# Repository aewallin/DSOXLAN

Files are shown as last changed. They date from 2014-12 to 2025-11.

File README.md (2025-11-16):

DSOXLAN
=======

This is a simple Ethernet interface-card for Agilent/Keysight
DSO-X 2000 and 3000 series oscilloscopes. The original Agilent/Keysight 
DSOXLAN module (about 326 euros + VAT as of December 2014)
also includes VGA output, while this simple card provides only LAN.

Many thanks to "georges80" on the EEVBlog forum
for the original schematic and PCB layout.

Components:
* Ethernet jack, WÜRTH 7499010121A
* 2pcs 470R 0805 resistor
* 1pcs 10R 0805 resistor
* 1pcs 1n 0805 capacitor

Files:
* Kicad: schematic, PCB, project, cmp, netlist
* non-standard footprints in /footprints: Ethernet magjack, 2x40-pin card-edge connector.

3D print components for case obtained from

https://www.eevblog.com/forum/projects/diy-dsoxlan-interface-for-keysight-oscilloscopes/msg4323214/#msg4323214

The mounting holes for the screws are 3.2 mm in diameter, so M3 screws
fit well.

Apparently they have been authored by Jay_Diddy_B.

Released under the CERN OHL. See http://ohwr.org/cernohl

Images
======

Using the 3D printed front cover and spacers, the entire module looks like:

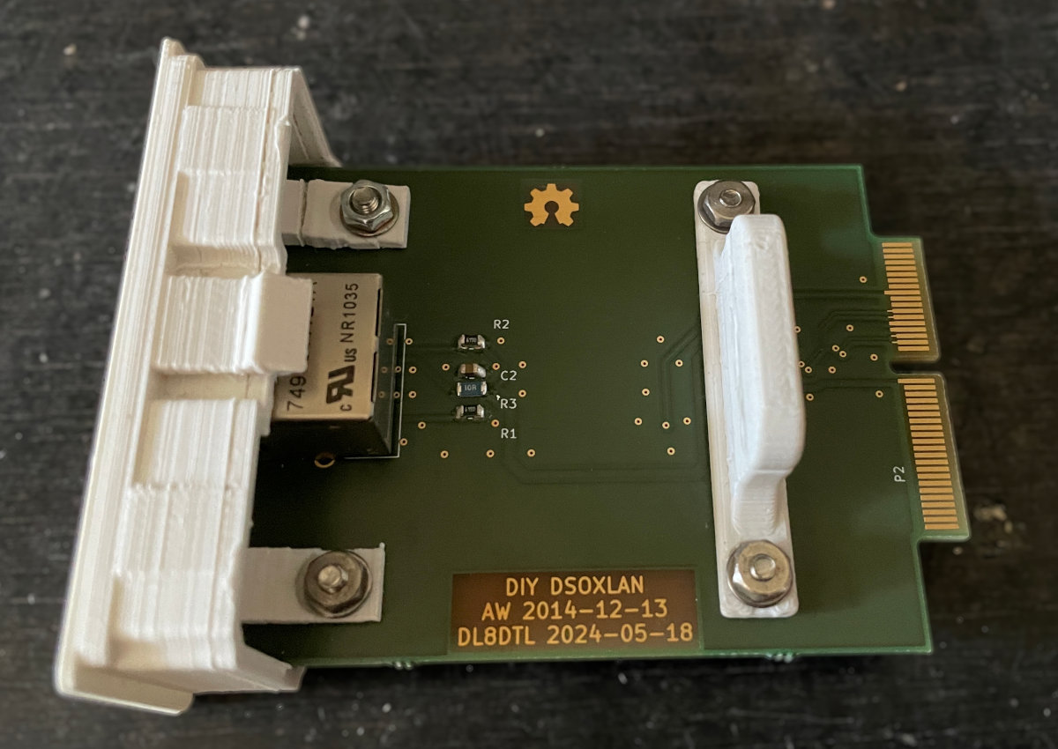
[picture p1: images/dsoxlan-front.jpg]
DSOXLAN front side

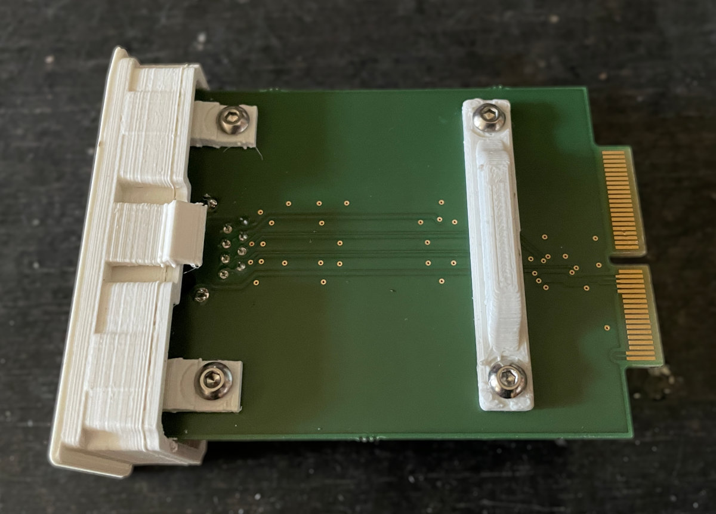
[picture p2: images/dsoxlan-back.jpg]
DSOXLAN back side


The oscilloscope features a built-in HTTP server.
The LAN settings page from the oscilloscope:

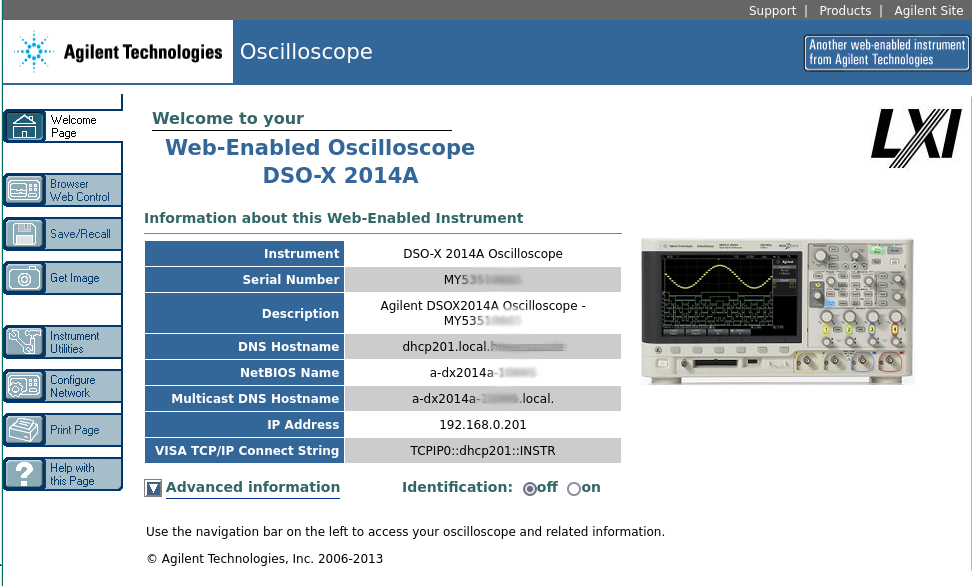
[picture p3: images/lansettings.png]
DSO-X LAN settings


There are also options for remote control straight from the HTTP
server. Some of them require Java, but when selecting the "Tablet"
mode, it offers an HTML5 control option:

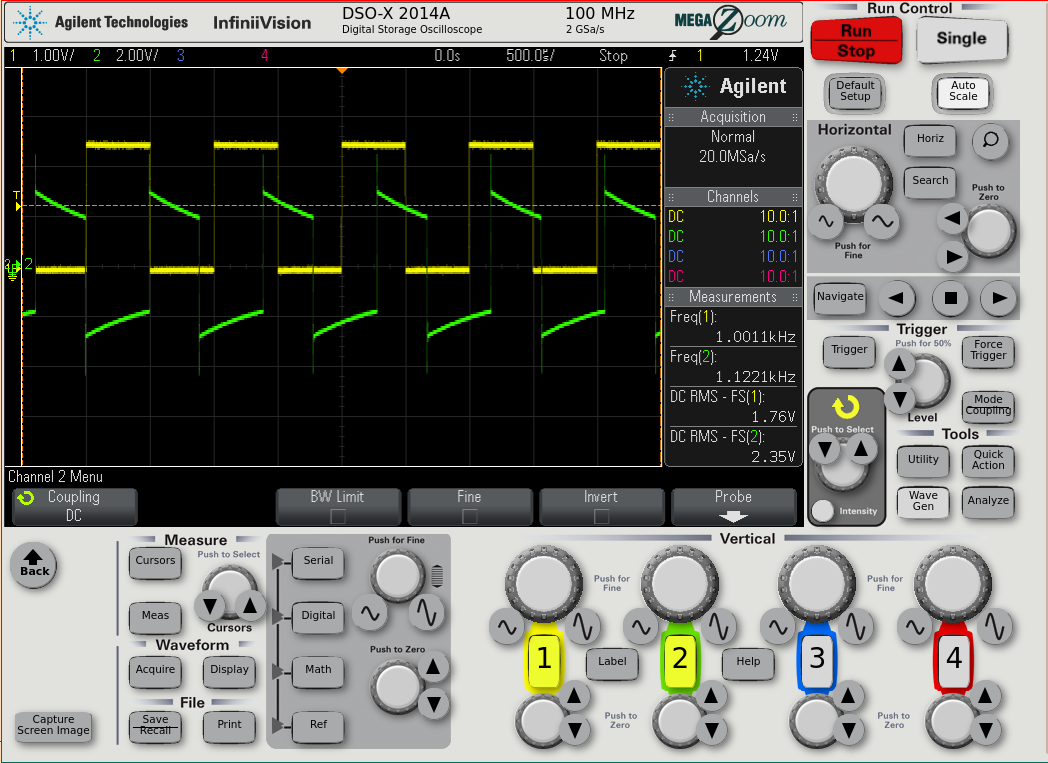
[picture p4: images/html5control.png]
DSO-X HTML5 screen


(Note: the above module has been built using a slightly different version
of the Würth RJ45 jack, 7499011121A. If anyone wants to use exactly
these, see https://github.com/dl8dtl/DSOXLAN/tree/WE7499011121A )

Links
=====
* https://web.archive.org/web/20200225205940/http://anagram.net/nuts/DSOXLAN/
* http://www.anderswallin.net/2014/12/diy-dsoxlan/

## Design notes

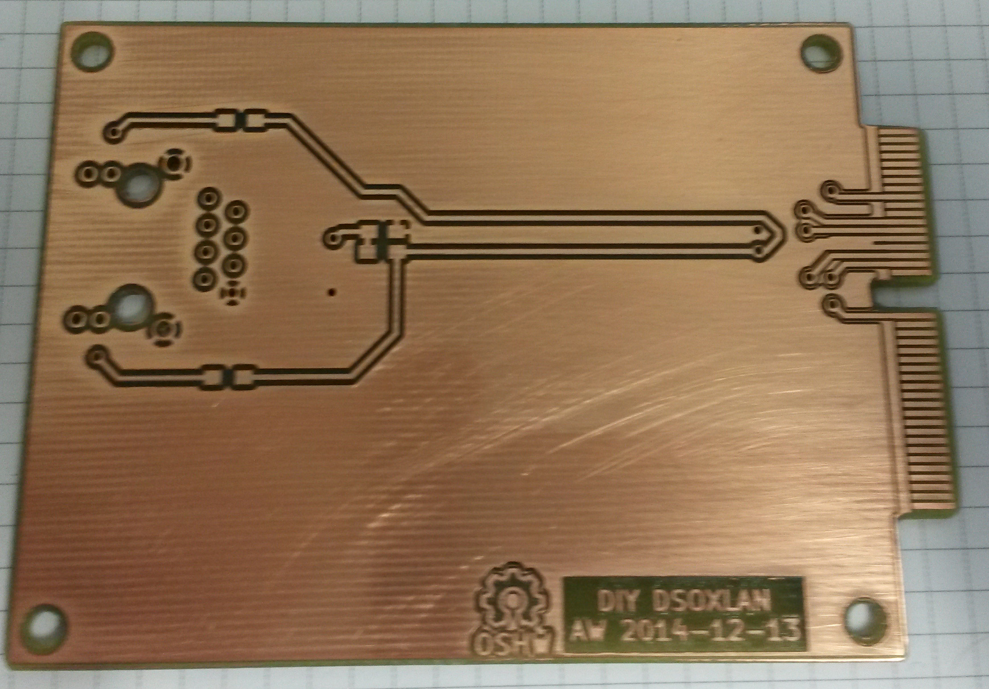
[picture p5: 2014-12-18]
dsoxlan_pcb_2014-12-17.jpg

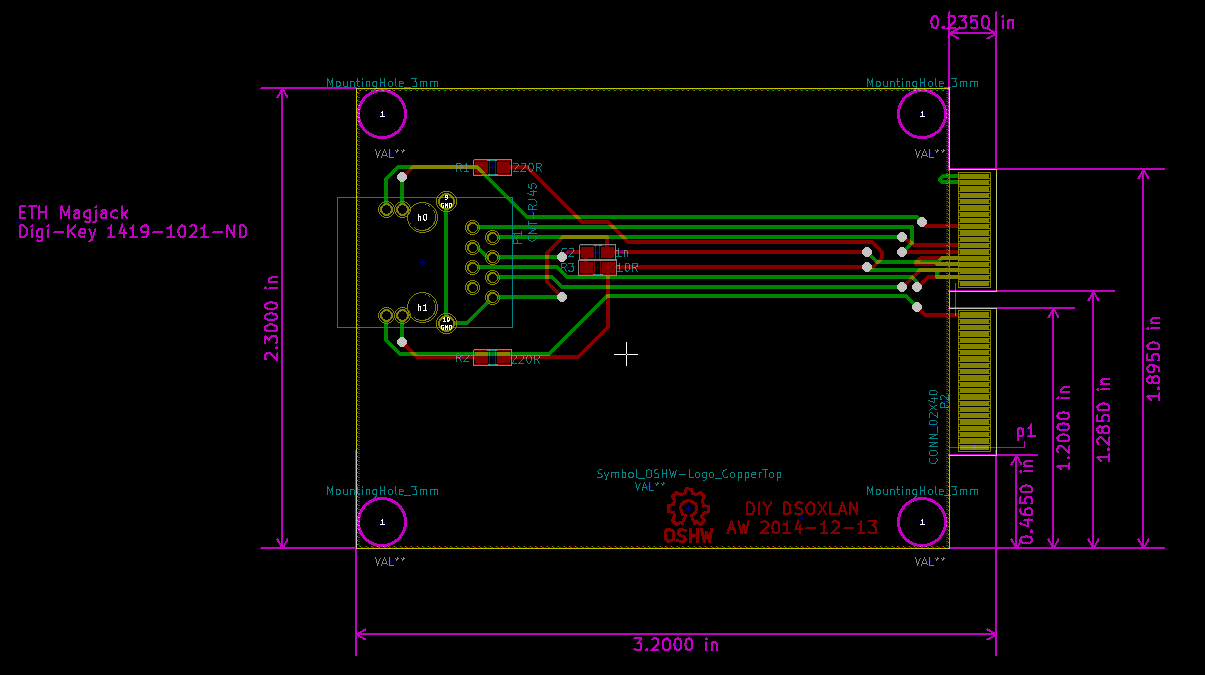
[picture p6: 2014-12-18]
dsoxlan_kicad_pcb.png

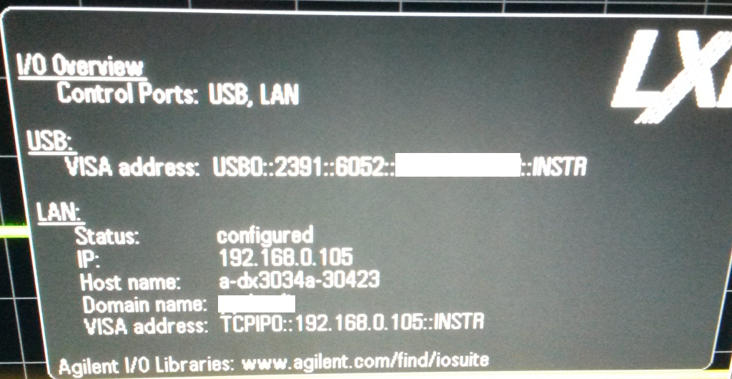
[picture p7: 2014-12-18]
dsoxlan_LAN-settings.jpg

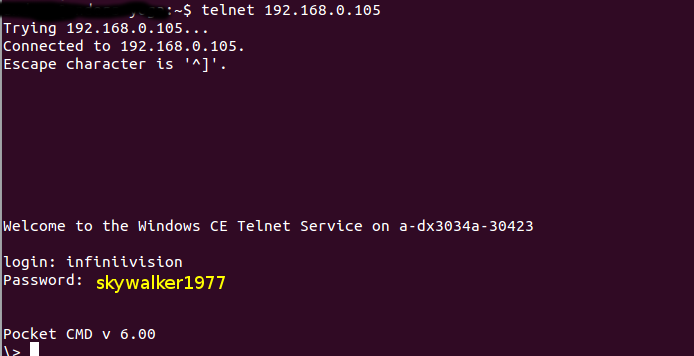
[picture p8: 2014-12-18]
dsoxlan_telnet.png

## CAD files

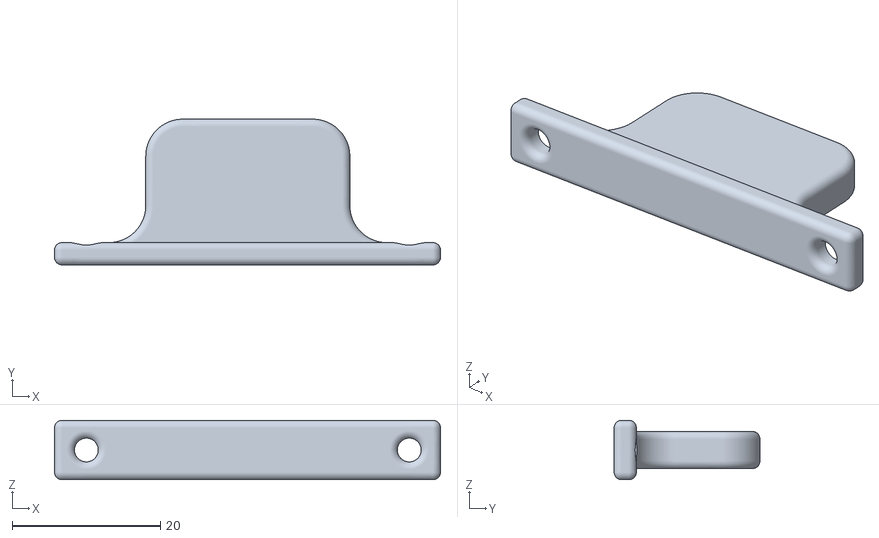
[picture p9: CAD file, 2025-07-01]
3Dmodels/Spacer 2b.stl
52.0 x 19.6 x 8.00

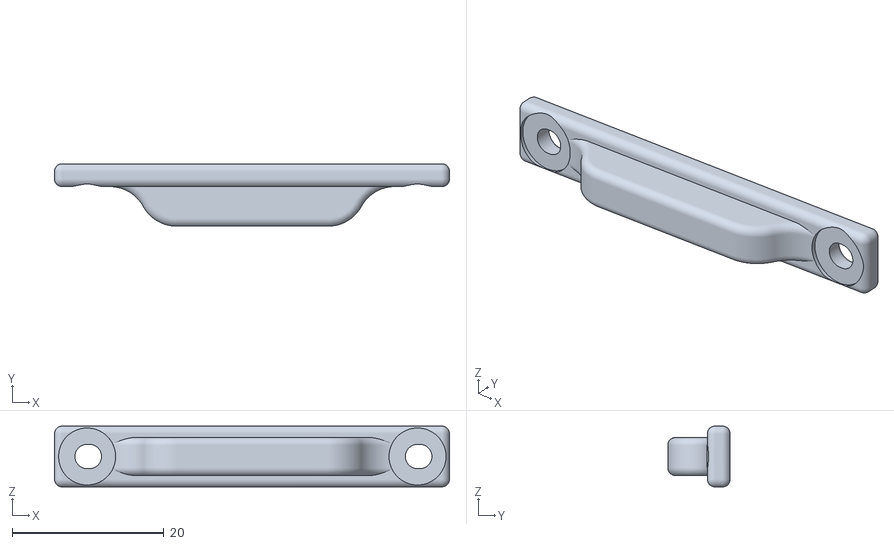
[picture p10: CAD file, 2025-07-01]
3Dmodels/Spacer 1a.stl
52.0 x 8.21 x 8.00

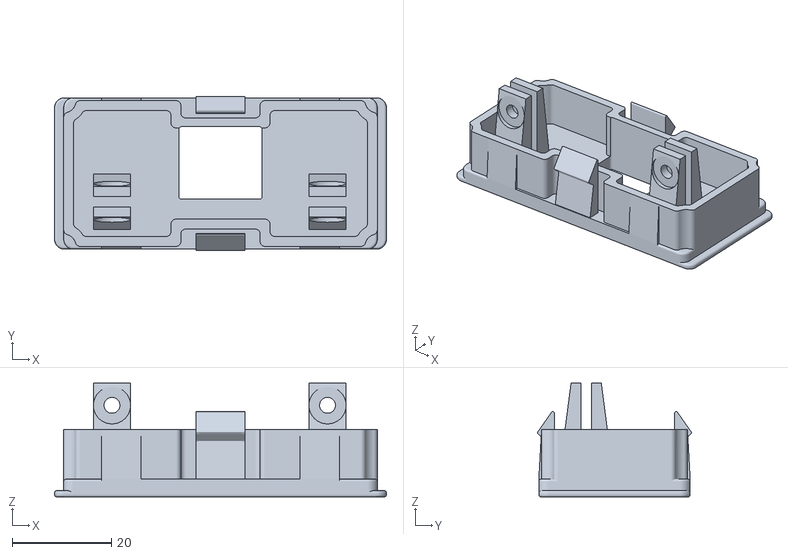
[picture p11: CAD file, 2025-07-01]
3Dmodels/Lid.stl
67.0 x 31.1 x 23.0

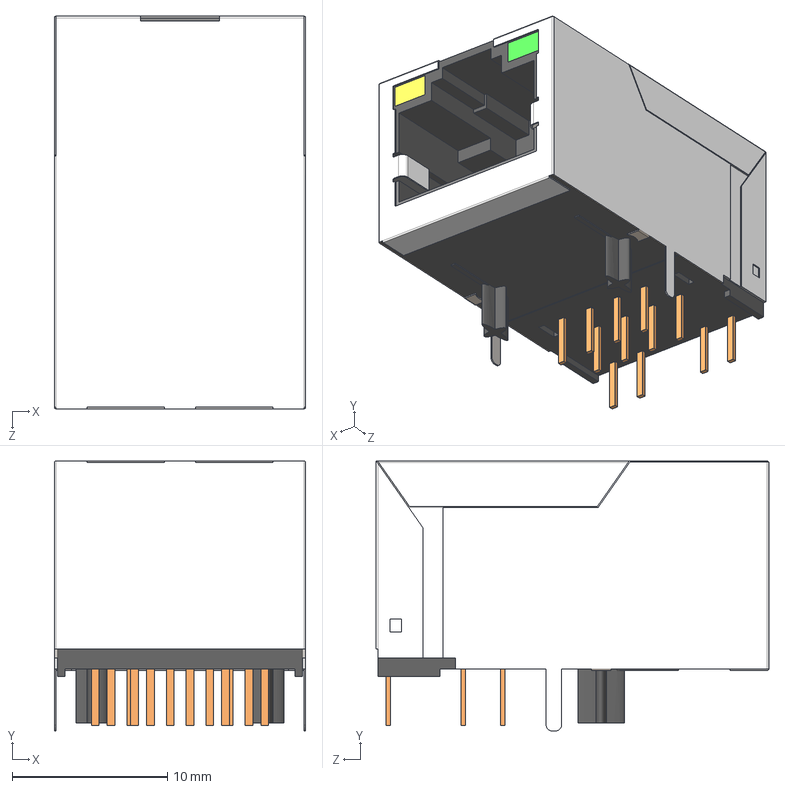
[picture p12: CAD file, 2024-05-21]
3Dmodels/7499010121A.stp
16.2 x 17.4 x 25.3 mm

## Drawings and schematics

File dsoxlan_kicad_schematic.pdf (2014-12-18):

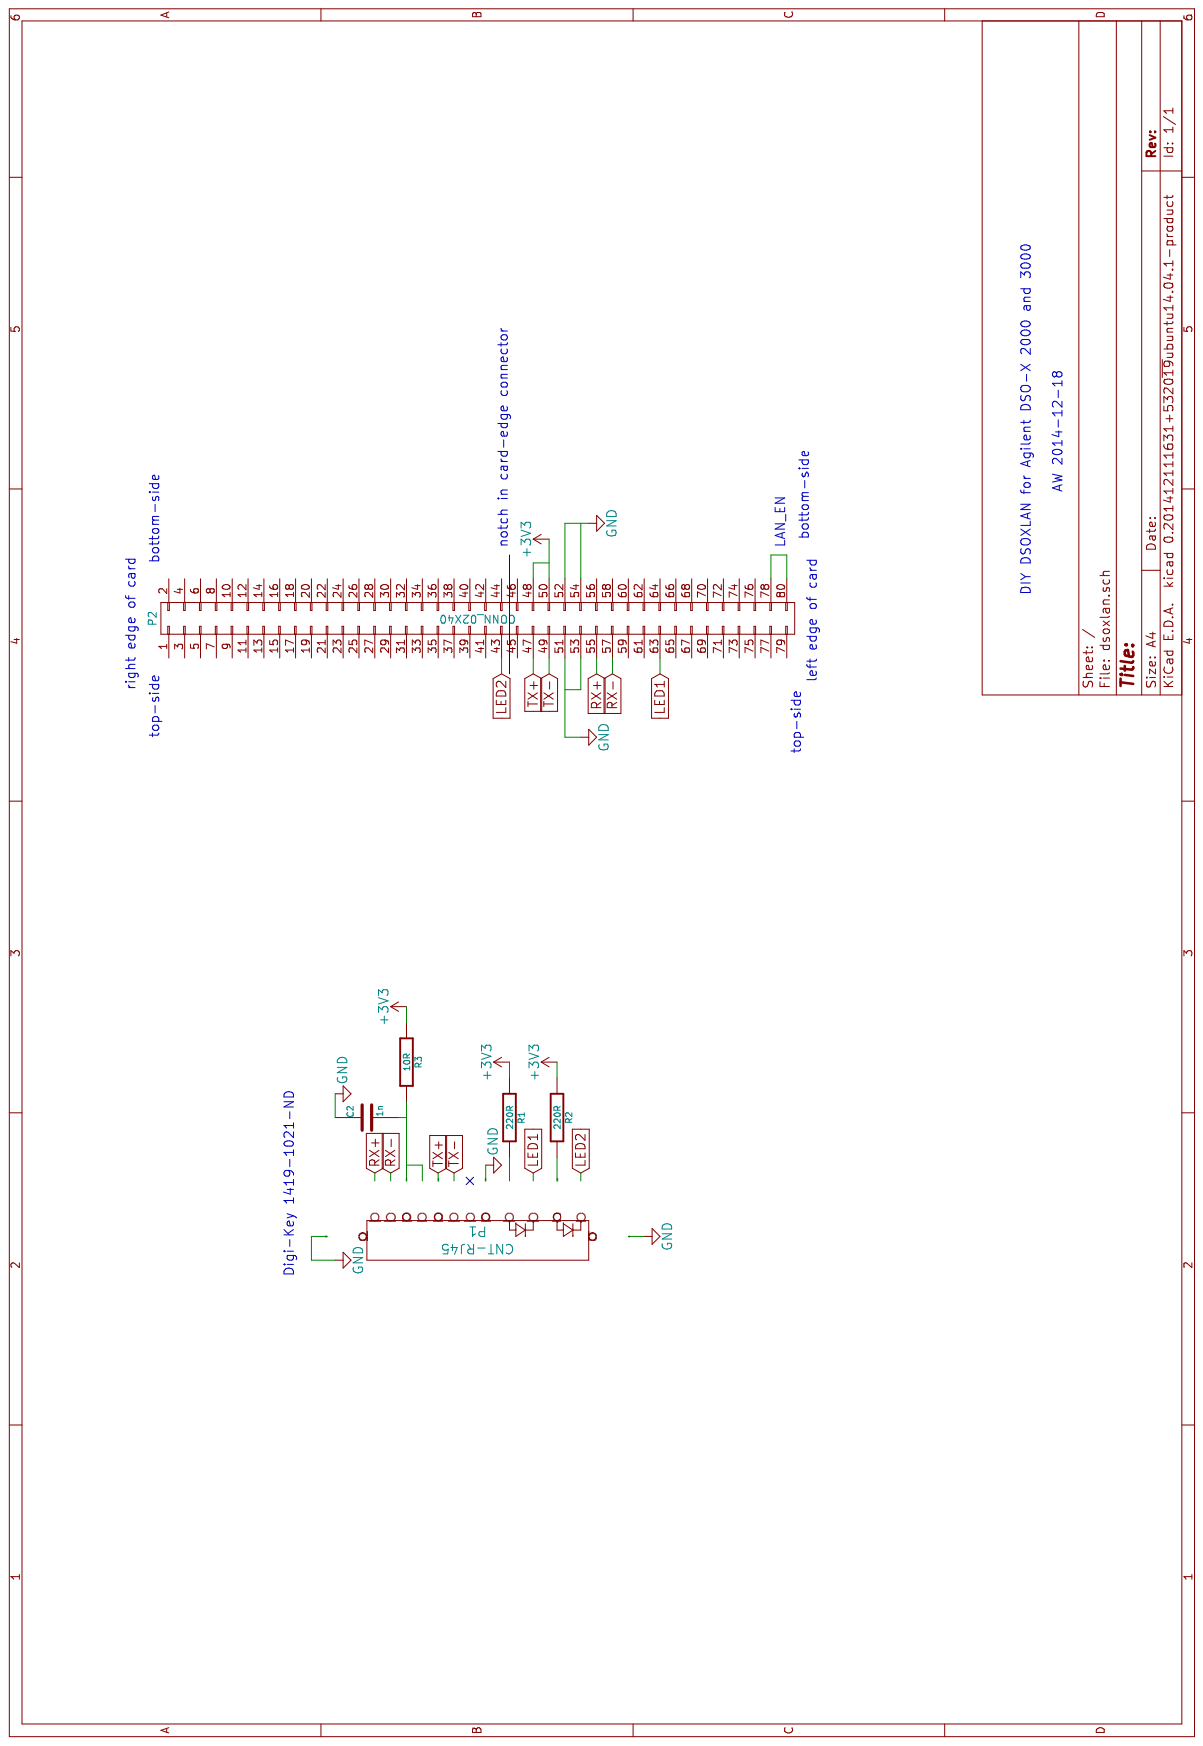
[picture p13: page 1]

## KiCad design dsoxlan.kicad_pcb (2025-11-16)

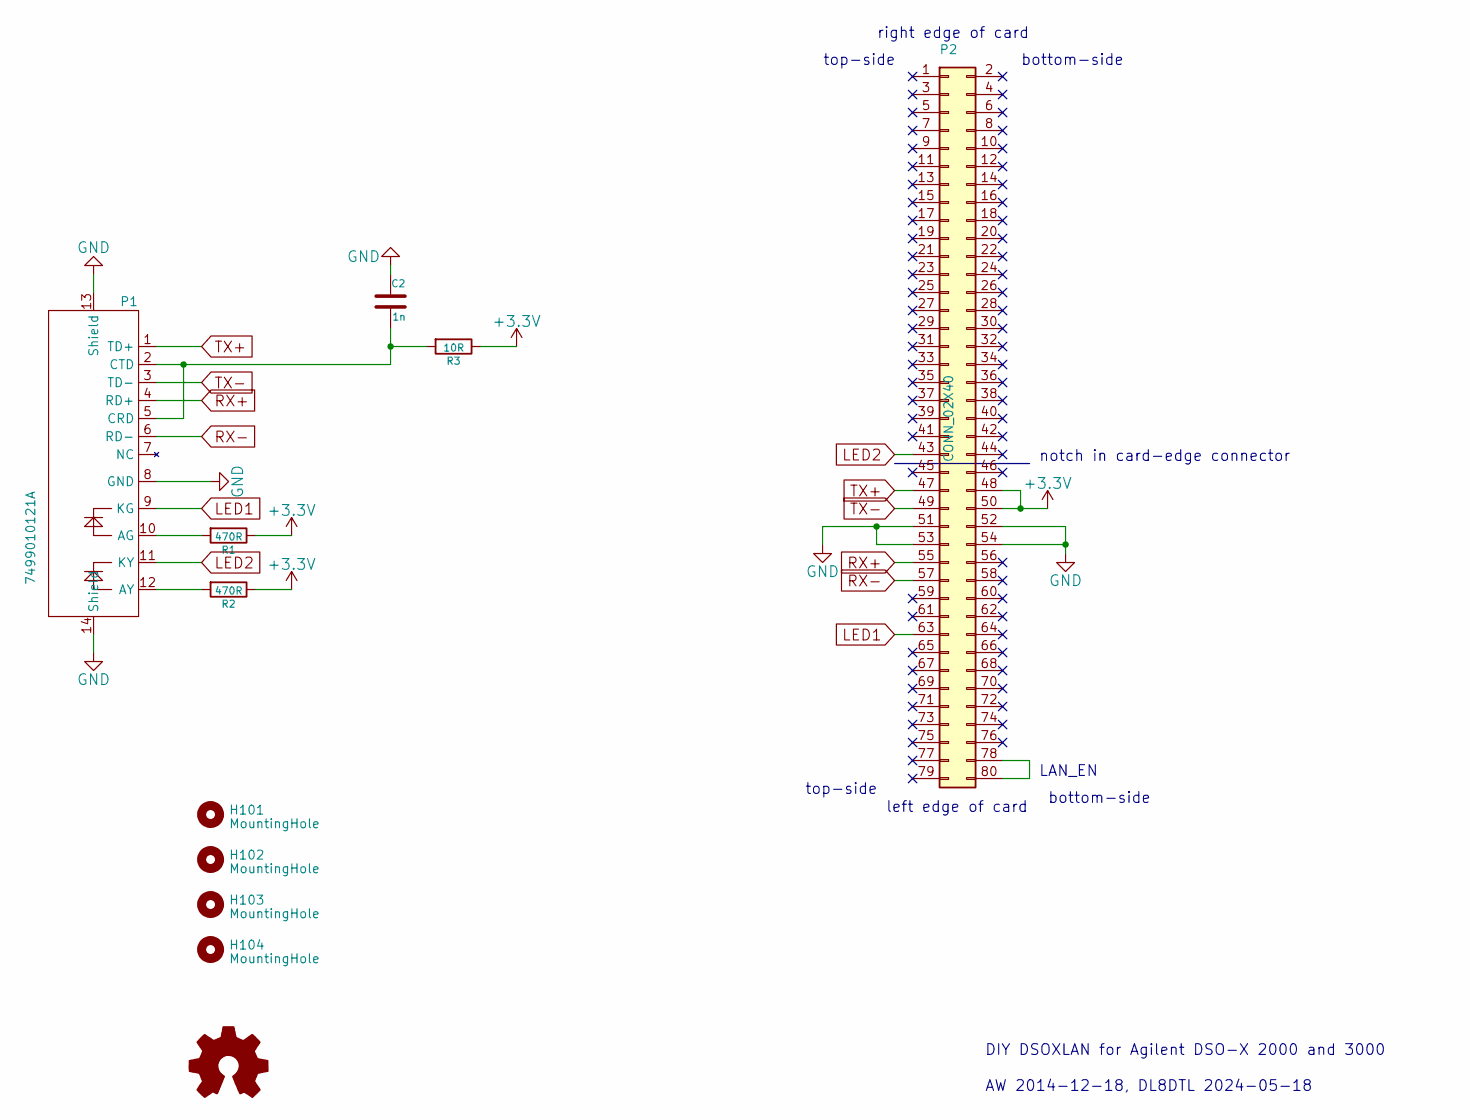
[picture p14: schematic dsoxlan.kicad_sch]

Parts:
C2: 1n; C_0805_2012Metric_Pad1.18x1.45mm_HandSolder
H101, H102, H103, H104: MountingHole; MountingHole_3.2mm_M3_ISO7380
P1: 7499010121A; WURTH-7499010121A
P2: CONN_02X40; cardedge_40x2
R1, R2: 470R; R_0805_2012Metric_Pad1.20x1.40mm_HandSolder
R3: 10R; R_0805_2012Metric_Pad1.20x1.40mm_HandSolder
SYM101: Logo_Open_Hardware_Small; OSHW-Symbol_6.7x6mm_Copper

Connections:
+3.3V: P2.48, P2.50, R1.1, R2.1, R3.1
GND: C2.1, P1.8 (GND), P1.13 (Shield), P1.14 (Shield), P2.51, P2.52, P2.53, P2.54
LED1: P1.9 (KG), P2.63
LED2: P1.11 (KY), P2.43
unnamed: P1.10 (AG), R1.2
unnamed: P1.12 (AY), R2.2
unnamed: C2.2, P1.2 (CTD), P1.5 (CRD), R3.2
unnamed: P2.78, P2.80
RX+: P1.4 (RD+), P2.55
RX-: P1.6 (RD-), P2.57
TX+: P1.1 (TD+), P2.47
TX-: P1.3 (TD-), P2.49

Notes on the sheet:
bottom-side
top-side
left edge of card
DIY DSOXLAN for Agilent DSO-X 2000 and 3000
AW 2014-12-18, DL8DTL 2024-05-18
right edge of card
notch in card-edge connector
LAN_EN

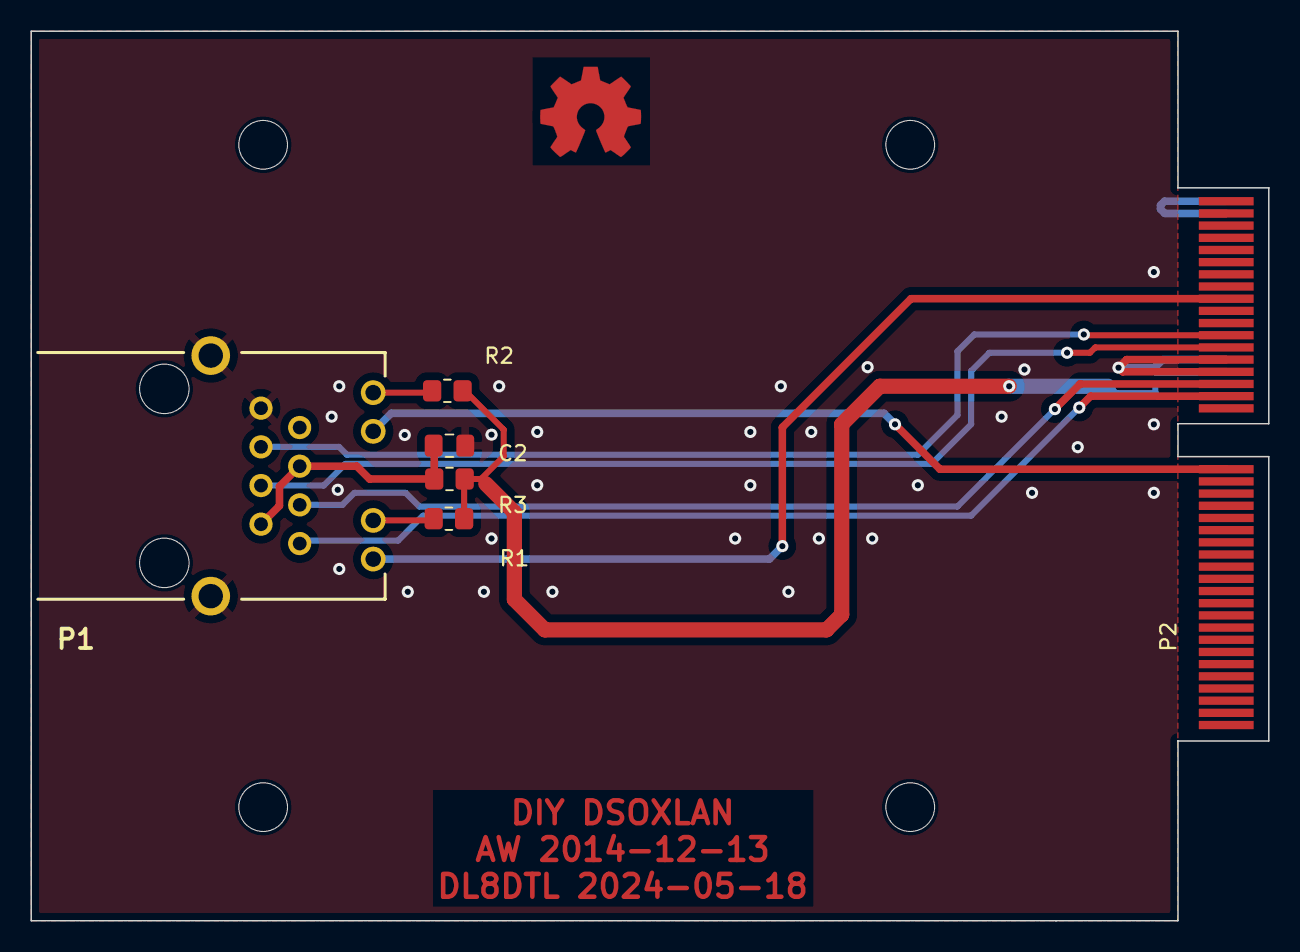
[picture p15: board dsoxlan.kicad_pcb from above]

Board: 2 copper layers, 81.3 x 58.4 mm, 11 parts (0 on the bottom side), 12 nets.

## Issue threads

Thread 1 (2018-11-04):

migrate to Kicad 5

aewallin, 2018-11-04:
The project should be moved to kicad 5.

The automatic remapping of symbols does not seem to work very well for me on Kicad 5.0.1.

on the PCB side the mounting-holes don't look right in Kicad 5.0.1.

dl8dtl, 2024-05-21:
That one can be closed now, as PR #3 contained all the necessary changes already.

Closed 2024-08-29.

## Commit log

2014-12-18 footprints for magjack and card-edge-connector
2014-12-18 gerbers and drill-file
    [dsoxlan-B_Cu.gbr, dsoxlan-Edge_Cuts.gbr, dsoxlan-F_Cu.gbr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]
2014-12-18 initial commit of kicad sources and pdf/jpg/png images/output
    [dsoxlan.kicad_pcb, dsoxlan.sch]
2014-12-18 schematic in pdf format
2024-05-17 First upgrade step: fix schematic
    Create new symbol for ethernet jack, previous one was not
    migrated.
    Fix library names for remaining parts.
    Rename all project files to their new .kicad_* suffix.
    [dsoxlan.kicad_sch, dsoxlan.sch]
2024-05-18 Basic upgrade to Kicad 7+
    Symbols had to be recreated because they were not part of
    original dataset.
    Footprint library now needs to end in .pretty
    Still many DRC warnings, but the basic result ought to be
    the same as before now.
    [dsoxlan.kicad_pcb, dsoxlan.kicad_sch]
2024-05-18 DRC fixup: remove silkscreen from outside board area
2024-05-18 Update PCB with updated components
    [dsoxlan.kicad_pcb]
2024-05-18 More silkscreen removal
    Move comment line into "User Comments" layer
2024-05-18 More silkscreen removal
    No point in trying to print silkscreen over a hole
2024-05-18 DSC fixup
    Replace all objects by new ones from the current libraries
    shipped by Kicad.
    This causes a slightly different OSHW (Opensource Hardware)
    logo to be used in the PCB.
    To maintain schematic parity, all mechanical objects on the
    PCB (mounting holes and OSHW logo) have their schematic
    counterparts now.
    [dsoxlan.kicad_pcb, dsoxlan.kicad_sch]
2024-05-18 Recreate Gerber files
    This now also includes Gerber files used for production at
    commercial PCB facilities:
    * solder masks
    * front silkscreen
    Drill files have been separated into PTH and NPTH files.
    [dsoxlan-B_Cu.gbr, dsoxlan-B_Mask.gbr, dsoxlan-Edge_Cuts.gbr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]
2024-05-18 Add symbol for Bel Fuse 08B0-1X1T-36-F
2024-05-18 Add footprint for Bel Fuse 08B0-1X1T-36-F
    Footprint obtained from Samacsys, but taken with changes:
    * mounting holes instead of pins 11/12
    * add courtyard
    * restrict silkscreen to inner area
2024-05-18 Replace RJ45 jack by Bel Fuse 08B0-1X1T-36-F
    The old TE Connectivity device is no longer available.
    Found another one that contains similar magnetics and
    termination as the TE one.
    [dsoxlan.kicad_pcb, dsoxlan.kicad_sch]
2024-05-18 Regenerate Gerbers
    [dsoxlan-B_Cu.gbr, dsoxlan-B_Mask.gbr, dsoxlan-Edge_Cuts.gbr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]
2024-05-18 Add STP 3D model for Bel Fuse RJ45 jack
    [08B0-1X1T-36-F.stp]
2024-05-18 Remove silkscreen prints for mounting holes
    [dsoxlan-B_Cu.gbr, dsoxlan-B_Mask.gbr, dsoxlan-Edge_Cuts.gbr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]
2024-05-18 Remove soldermask from OSHW logo and text at bottom
    [dsoxlan.kicad_pcb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]
2024-05-19 Remove solder mask from edge connector
    [dsoxlan.kicad_pcb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]
2024-05-20 Replace RJ45 jack by Würth 7499010121A
    This one appears to be readily available at various distributors.
    Also add 3D print models for case parts, obtained from
    https://www.eevblog.com/forum/projects/diy-dsoxlan-interface-for-keysight-oscilloscopes/msg4323214/#msg4323214
    apparently authored by Jay_Diddy_B.
    Adapted layout to fit these models.
    [08B0-1X1T-36-F.stp, 7499010121A.stp, dsoxlan.kicad_pcb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]
2024-05-20 Update Gerber and Excellon files
    [dsoxlan-B_Cu.gbr, dsoxlan-B_Mask.gbr, dsoxlan-Edge_Cuts.gbr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]
2024-05-20 Remove some useless silkscreen texts from mechanical parts
    [dsoxlan.kicad_pcb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]
2024-05-21 open with kicad8
    [dsoxlan.kicad_pcb, dsoxlan.kicad_sch]
2024-08-25 Add a LICENSE.txt file
    The file is a copy of the CERN-OHL-P v2. Adding it to the tree
    is basically required by the license itself, as it ought to be
    bundled with the files released under it.
    While being here, I have also been asked to comment on the screws
    used, so added a sentence about them.
    Also added the *-lib-table files since they describe the
    project-local libraries for KiCad.
    This is supposed to fix issue #5
2025-06-30 Update Readme.md BOM to match schematic/PCB values
2025-07-01 Add STL files for easier 3D printing - By Jay_Diddy_BTopic on EEVBlog - https://www.eevblog.com/forum/projects/diy-dsoxlan-interface-for-keysight-oscilloscopes/msg4994941/#msg4994941
    [Lid.stl, Spacer 1a.stl, Spacer 2b.stl]
2025-11-16 update to kicad9
    [dsoxlan.kicad_pcb, dsoxlan.kicad_sch]
